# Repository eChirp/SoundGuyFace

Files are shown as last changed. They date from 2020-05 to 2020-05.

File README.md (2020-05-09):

# SoundGuyFace
This is a simple USB audio interface using the Texas Instruments 2912A. The IC is a single chip solution for standard audio needs with a computer. Professional microphones use the XLR connector and have differential signals. The SoundGuyFace takes both, microphone and instrument 1/4" cables. A dedicated gain knob let you choose the input sensitivity.

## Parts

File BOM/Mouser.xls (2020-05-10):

Mfr Part Number (Input) | Manufacturer Part Number | Mouser Part Number | Manufacturer Name | Description | Quantity 1 | Unit Price 1 | Quantity 2 | Unit Price 2 | Quantity 3 | Unit Price 3 | Quantity 4 | Unit Price 4 | Quantity 5 | Unit Price 5 | Order Quantity | Order Unit Price | Min./Mult. | Availability | Lead Time in Days | Lifecycle | NCNR | RoHS | Pb Free | Package Type | Datasheet URL | Product Image | Design Risk
 |  | 710-860020373010 | Wurth Elektronik |  | 2
 |  | 581-08055D475KAT2A | AVX |  | 4
 |  | 710-885012205052 | Wurth Elektronik |  | 2
 |  | 710-860020772010 | Wurth Elektronik |  | 2
 |  | 710-885012005007 | Wurth Elektronik |  | 1
 |  | 710-860010672002 | Wurth Elektronik |  | 1
 |  | 963-UMK212BJ105MG-T | Taiyo Yuden |  | 1
 |  | 710-885012005013 | Wurth Elektronik |  | 2
 |  | 810-C1005X5R1A335K0C | TDK |  | 2
 |  | 791-0603N251J500CT | Walsin |  | 1
 |  | 963-LMK105BJ105MVHF | Taiyo Yuden |  | 9
 |  | 80-C0402C390J5G | KEMET |  | 2
 |  | 583-FM5819 | Rectron |  | 3
 |  | 604-AA3021ES | Kingbright |  | 1
 |  | 604-AA3021SGS | Kingbright |  | 1
 |  | 550-20384 |  |  | 1
 |  | 568-NCJ6FA-H-0 | Neutrik |  | 1
 |  | 490-UJ2-MIBH-4-MSMT |  |  | 1
 |  | 710-74404064220 | Wurth Elektronik |  | 1
 |  | 710-74479276210C | Wurth Elektronik |  | 1
 |  | 71-CRCW04021K00FKEDC | Vishay / Dale |  | 6
 |  | 71-CRCW04026K80FKED | Vishay / Dale |  | 3
 |  | 755-SFR01MZPF3301 | ROHM Semiconductor |  | 4
 |  | 71-CRCW040247K0FKEDC | Vishay / Dale |  | 2
 |  | 667-ERJ-2RKD18R0X | Panasonic |  | 2
 |  | 755-SFR01MZPF2702 | ROHM Semiconductor |  | 1
 |  | 603-RC0100JR-071K5L | Yageo |  | 1
 |  | 755-SFR01MZPF22R0 | ROHM Semiconductor |  | 2
 |  | 755-SFR01MZPJ105 | ROHM Semiconductor |  | 2
 |  | 71-CRCW040220K0FKEDC | Vishay / Dale |  | 1
 |  | 595-INA333AIDGKR | Texas Instruments |  | 1
 |  | 595-TPS61040DBVR | Texas Instruments |  | 1
 |  | 81-CSTNR6M00GH5L000R |  |  | 1

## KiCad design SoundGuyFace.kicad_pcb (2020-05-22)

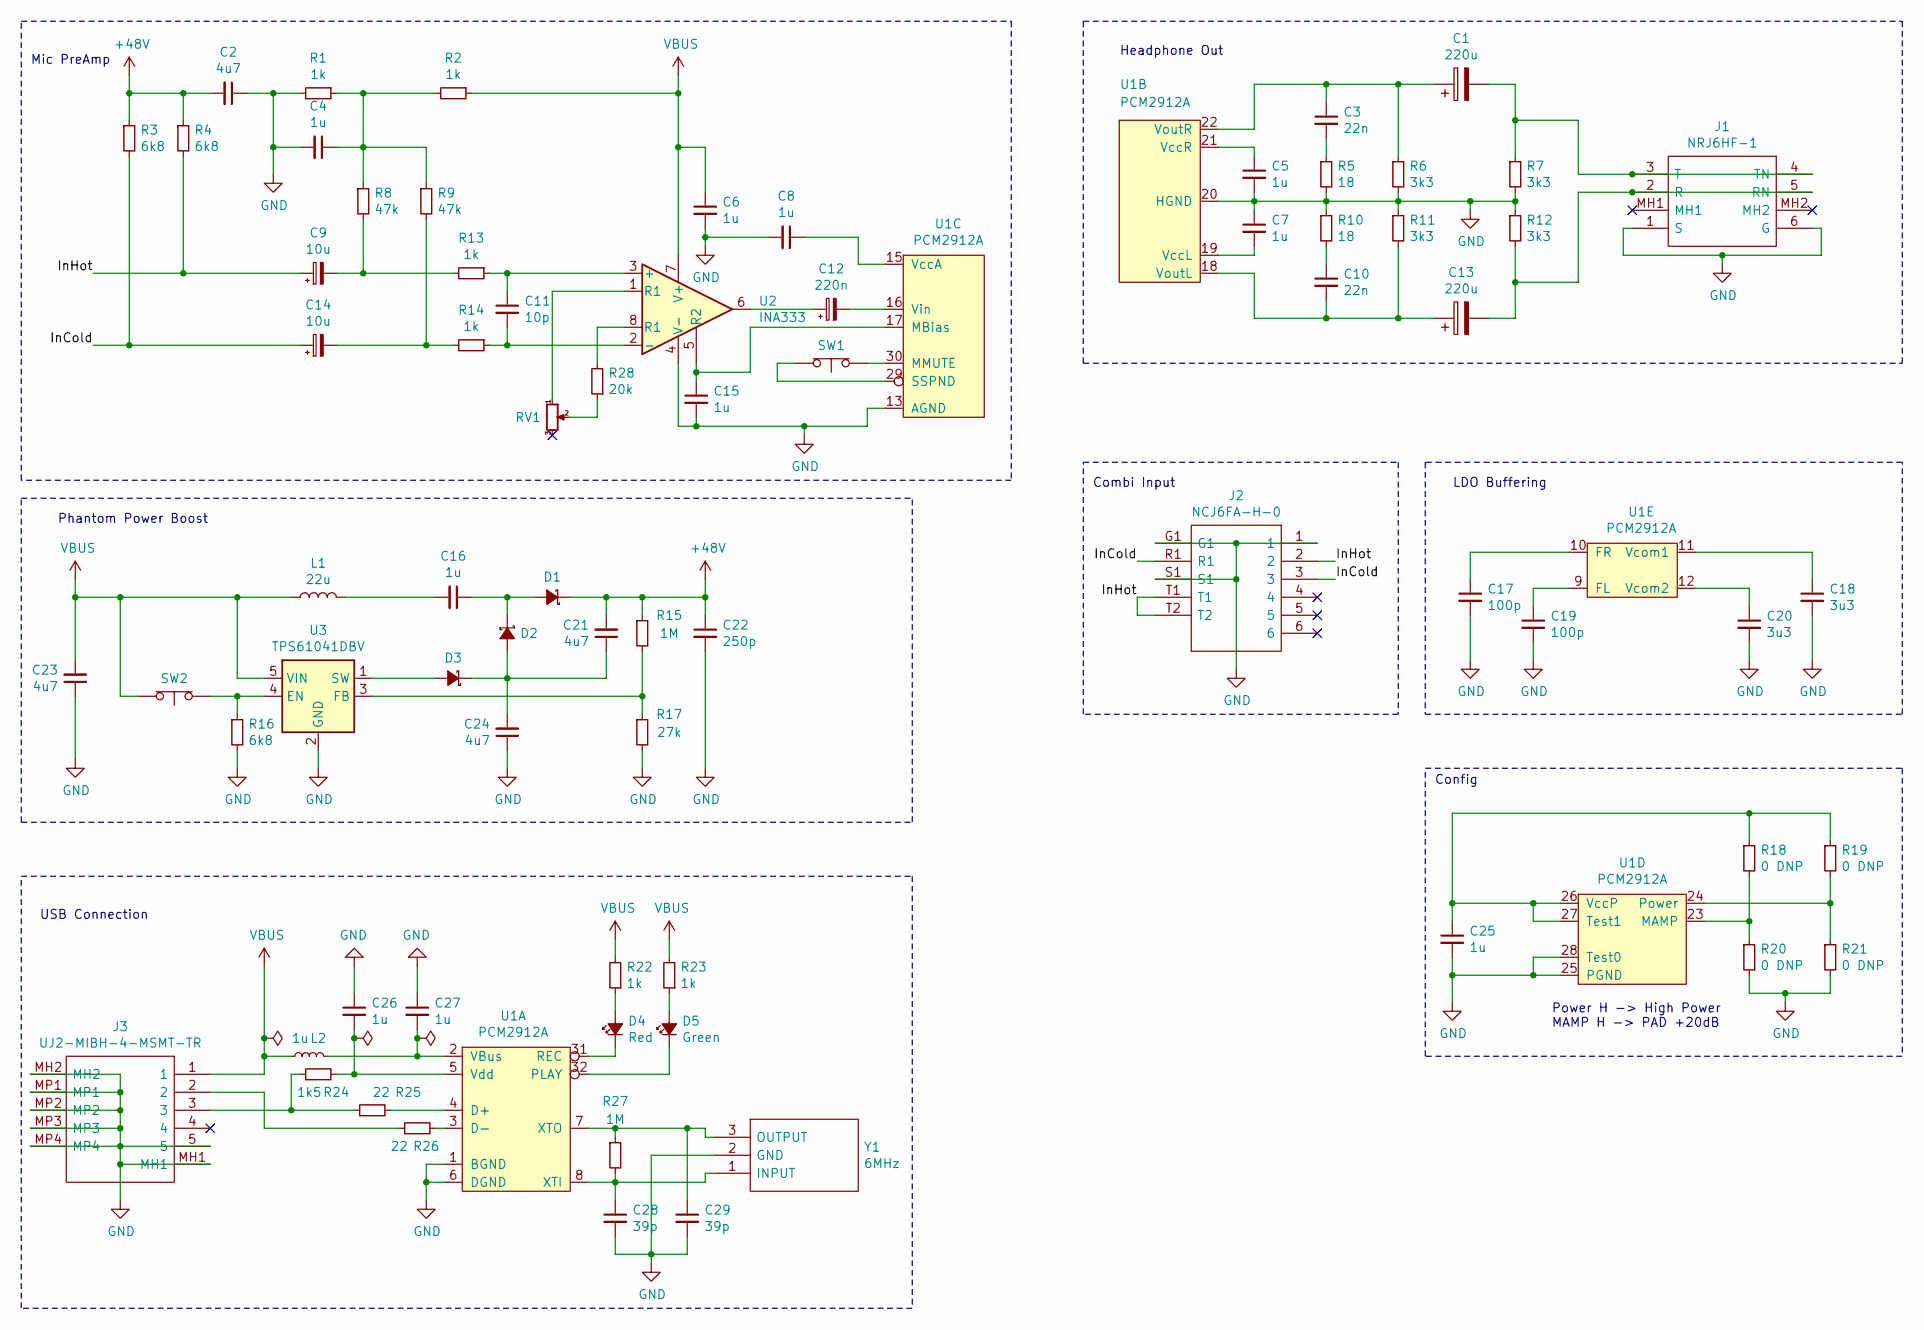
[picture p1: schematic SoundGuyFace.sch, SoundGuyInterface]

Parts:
C1, C13: 220u; CP_Radial_D6.3mm_P2.50mm; Manufacturer Part ID 860020373010; Mouser ID 710-860020373010
C2, C21, C23, C24: 4u7; C_0402_1005Metric; Manufacturer Part ID 08055D475KAT2A; Mouser ID 581-08055D475KAT2A
C3, C10: 22n; C_0402_1005Metric; Manufacturer Part ID 885012205052; Mouser ID 710-885012205052
C4, C5, C6, C7, C8, C15, C25, C26, C27: 1u; C_0402_1005Metric; Manufacturer Part ID LMK105BJ105MVHF; Mouser ID 963-LMK105BJ105MVHF
C9, C14: 10u; CP_Radial_D5.0mm_P2.00mm; Manufacturer Part ID 860020772010; Mouser ID 710-860020772010
C11: 10p; C_0402_1005Metric; Manufacturer Part ID 885012005007; Mouser ID 710-885012005007
C12: 220n; CP_Radial_D5.0mm_P2.00mm; Manufacturer Part ID 860010672002; Mouser ID 710-860010672002
C16: 1u; C_0805_2012Metric; Manufacturer Part ID UMK212BJ105MG-T; Mouser ID 963-UMK212BJ105MG-T
C17, C19: 100p; C_0402_1005Metric; Manufacturer Part ID 885012005013; Mouser ID 710-885012005013
C18, C20: 3u3; C_0402_1005Metric; Manufacturer Part ID C1005X5R1A335K050BC; Mouser ID 810-C1005X5R1A335K0C
C22: 250p; C_0603_1608Metric; Manufacturer Part ID 0603N251J500CT; Mouser ID 791-0603N251J500CT
C28, C29: 39p; C_0402_1005Metric; Manufacturer Part ID C0402C390J5GACTU; Mouser ID 80-C0402C390J5G
D1, D2, D3: D_Schottky_Small_ALT; D_SMA_Handsoldering; Manufacturer Part ID FM5819-W; Mouser ID 583-FM5819
D4: Red; D_1210_3225Metric; Manufacturer Part ID AA3021ES; Mouser ID 604-AA3021ES
D5: Green; D_1210_3225Metric; Manufacturer Part ID AA3021SGS; Mouser ID 604-AA3021SGS
J1: NRJ6HF-1; NRJ6HF1; Mouser Part Number 550-20384
J2: NCJ6FA-H-0; NCJ6FAH0; Mouser Part Number 568-NCJ6FA-H-0
J3: UJ2-MIBH-4-MSMT-TR; UJ2MIBH4MSMTTR; Mouser Part Number 490-UJ2-MIBH-4-MSMT
L1: 22u; INDPM6060X450N; Manufacturer Part ID 74404064220; Mouser ID 710-74404064220
L2: 1u; L_0805_2012Metric; Manufacturer Part ID 74479276210C; Mouser ID 710-74479276210C
R1, R2, R13, R14, R22, R23: 1k; R_0402_1005Metric; Manufacturer Part ID CRCW04021K00FKEDC; Mouser ID 71-CRCW04021K00FKEDC
R3, R4, R16: 6k8; R_0402_1005Metric; Manufacturer Part ID CRCW04026K80FKED; Mouser ID 71-CRCW04026K80FKED
R5, R10: 18; R_0402_1005Metric; Manufacturer Part ID ERJ2RKD18R0X; Mouser ID 667-ERJ-2RKD18R0X
R6, R7, R11, R12: 3k3; R_0402_1005Metric; Manufacturer Part ID SFR01MZPF3301; Mouser ID 755-SFR01MZPF3301
R8, R9: 47k; R_0402_1005Metric; Manufacturer Part ID CRCW040247K0FKEDC; Mouser ID 71-CRCW040247K0FKEDC
R15, R27: 1M; R_0402_1005Metric; Manufacturer Part ID SFR01MZPJ105; Mouser ID 755-SFR01MZPJ105
R17: 27k; R_0402_1005Metric; Manufacturer Part ID SFR01MZPF2702; Mouser ID 755-SFR01MZPF2702
R18, R19, R20, R21: 0 DNP; R_0201_0603Metric
R24: 1k5; R_0402_1005Metric; Manufacturer Part ID RC0100JR-071K5L; Mouser ID 603-RC0100JR-071K5L
R25, R26: 22; R_0402_1005Metric; Manufacturer Part ID SFR01MZPF22R0; Mouser ID 755-SFR01MZPF22R0
R28: 20k; R_0402_1005Metric; Manufacturer Part ID CRCW040220K0FKEDC; Mouser ID 71-CRCW040220K0FKEDC
RV1: R_POT_Small; Potentiometer_Alps_RK097_Dual_Horizontal
SW1, SW2: SW_Push_Open; PinHeader_1x02_P2.54mm_Vertical
U1: PCM2912A; TQFP-32_7x7mm_P0.8mm
U2: INA333; VSSOP-8_3.0x3.0mm_P0.65mm; Manufacturer Part ID INA333AIDGKR; Mouser ID 595-INA333AIDGKR
U3: TPS61041DBV; SOT-23-5; Manufacturer Part ID TPS61040DBVR; Mouser ID 595-TPS61040DBVR
Y1: 6MHz; CSTNR6M00GH5L000R0; Mouser Part Number 81-CSTNR6M00GH5L000R

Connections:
+48V: C2.2, C21.2, C22.1, D1.1 (K), R3.1, R4.1, R15.1
/InCold: C14.1, J2.3, J2.R1, R3.2
/InHot: C9.1, J2.2, J2.T1, J2.T2, R4.2
GND: C2.1, C4.2, C5.2, C6.2, C7.1, C8.2, C15.2, C17.2, C18.2, C19.2, C20.2, C22.2, C23.1, C24.1, C25.2, C26.1, C27.1, C28.2, C29.2, J1.1 (S), J1.6 (G), J2.1, J2.G1, J2.S1, J3.5, J3.MH1, J3.MH2, J3.MP1, J3.MP2, J3.MP3, J3.MP4, R1.2, R5.2, R6.2, R7.2, R10.1, R11.1, R12.1, R16.2, R17.2, R20.2, R21.2, U1.1 (BGND), U1.6 (DGND), U1.13 (AGND), U1.20 (HGND), U1.25 (PGND), U1.28 (Test0), U2.4 (V-), U3.2 (GND), Y1.2 (GND)
unnamed: C1.1, C3.1, R6.1, U1.22 (VoutR)
unnamed: C1.2, J1.3 (T), J1.4 (TN), R7.1
unnamed: C3.2, R5.1
unnamed: C4.1, R1.1, R2.2, R8.1, R9.1
unnamed: C5.1, U1.21 (VccR)
unnamed: C7.2, U1.19 (VccL)
unnamed: C8.1, U1.15 (VccA)
unnamed: C9.2, R8.2, R13.2
unnamed: C10.1, R10.2
unnamed: C10.2, C13.1, R11.2, U1.18 (VoutL)
unnamed: C11.1, R13.1, U2.3 (+)
unnamed: C11.2, R14.1, U2.2 (-)
unnamed: C12.1, U2.6
unnamed: C12.2, U1.16 (Vin)
unnamed: C13.2, J1.2 (R), J1.5 (RN), R12.2
unnamed: C14.2, R9.2, R14.2
unnamed: C15.1, U1.17 (MBias), U2.5 (R2)
unnamed: C16.1, D1.2 (A), D2.1 (K)
unnamed: C16.2, L1.2
unnamed: C17.1, U1.10 (FR)
unnamed: C18.1, U1.11 (Vcom1)
unnamed: C19.1, U1.9 (FL)
unnamed: C20.1, U1.12 (Vcom2)
unnamed: C21.1, C24.2, D2.2 (A), D3.1 (K)
unnamed: C25.1, R18.1, R19.1, U1.26 (VccP), U1.27 (Test1)
unnamed: C26.2, R24.2, U1.5 (Vdd)
unnamed: C27.2, L2.2, U1.2 (VBus)
unnamed: C28.1, R27.2, U1.8 (XTI), Y1.1 (INPUT)
unnamed: C29.1, R27.1, U1.7 (XTO), Y1.3 (OUTPUT)
unnamed: D3.2 (A), U3.1 (SW)
unnamed: D4.1 (K), U1.31 (REC)
unnamed: D4.2 (A), R22.1
unnamed: D5.1 (K), U1.32 (PLAY)
unnamed: D5.2 (A), R23.1
unnamed: J3.2, R26.1
unnamed: J3.3, R24.1, R25.1
unnamed: R15.2, R17.1, U3.3 (FB)
unnamed 47: R16.1, SW2.2 (B), U3.4 (EN); also elsewhere on the board
unnamed: R18.2, R20.1, U1.23 (MAMP)
unnamed: R19.2, R21.1, U1.24 (Power)
unnamed: R25.2, U1.4 (D+)
unnamed: R26.2, U1.3 (D-)
unnamed: R28.1, RV1.2
unnamed: R28.2, U2.8 (R1)
unnamed: RV1.1, U2.1 (R1)
unnamed 56: SW1.1 (A), U1.29 (SSPND); also elsewhere on the board
unnamed 57: SW1.2 (B), U1.30 (MMUTE); also elsewhere on the board
VBUS: C6.1, C23.2, J3.1, L1.1, L2.1, R2.1, R22.2, R23.2, SW2.1 (A), U2.7 (V+), U3.5 (VIN); also elsewhere on the board

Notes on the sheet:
Power H -> High Power MAMP H -> PAD +20dB
LDO Buffering
Headphone Out
Config
Mic PreAmp
USB Connection
Combi Input
Phantom Power Boost

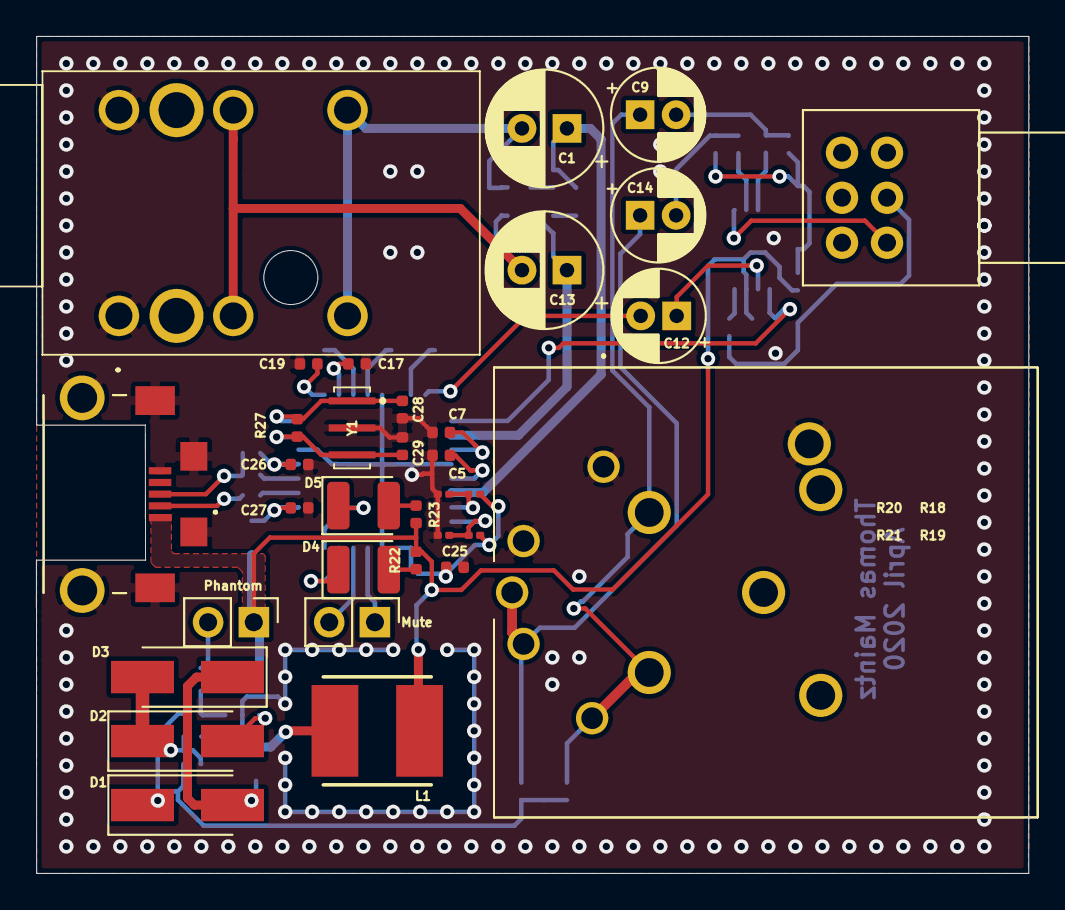
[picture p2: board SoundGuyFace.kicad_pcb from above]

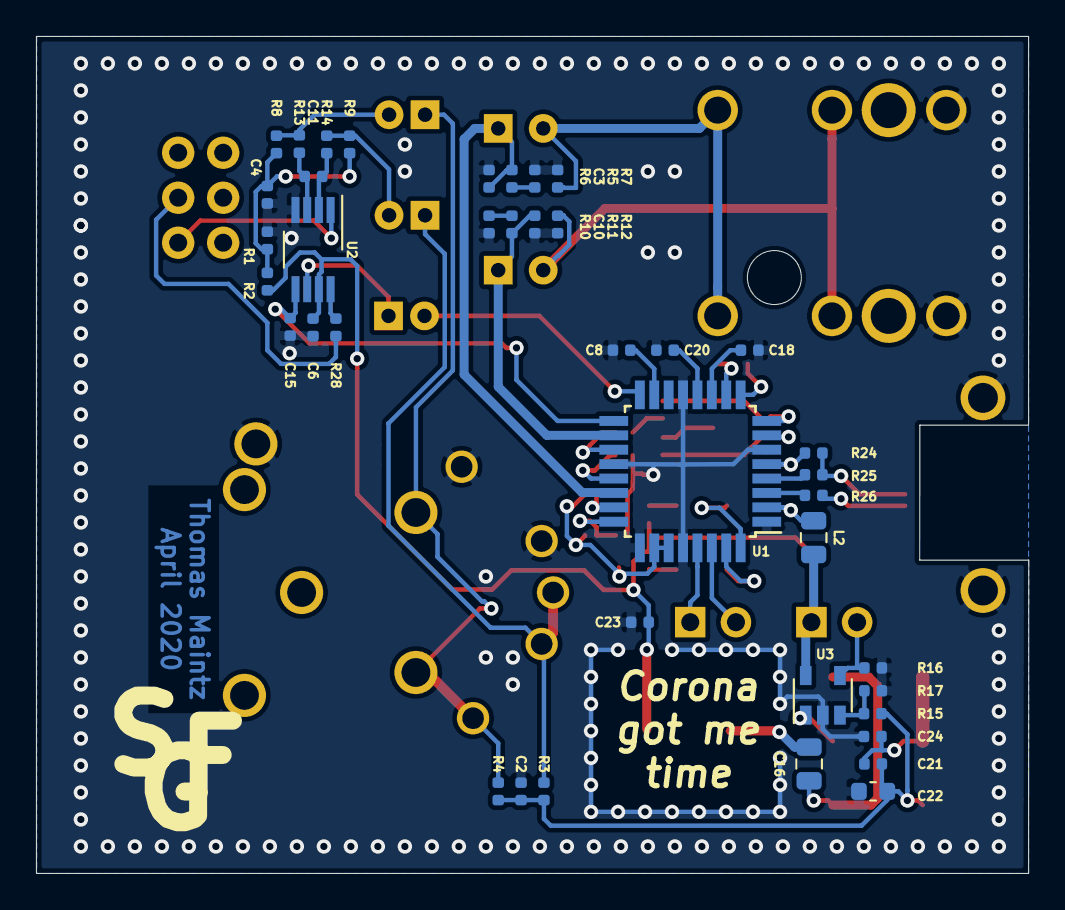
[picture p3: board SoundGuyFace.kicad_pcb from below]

Board: 2 copper layers, 55.1 x 46.5 mm, 74 parts (40 on the bottom side), 52 nets.

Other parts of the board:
Mute: SW_Push_Open; PinHeader_1x02_P2.54mm_Vertical
Phantom: SW_Push_Open; PinHeader_1x02_P2.54mm_Vertical

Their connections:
unnamed 47: Phantom.2; also elsewhere on the board
unnamed 56: Mute.1; also elsewhere on the board
unnamed 57: Mute.2; also elsewhere on the board
VBUS: Phantom.1; also elsewhere on the board

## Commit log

2020-05-09 Initial KiCAD project commit
    [SoundGuyFace.kicad_pcb, SoundGuyFace.sch]
2020-05-10 Small schematic changes and first PCB layout done
    [SoundGuyFace.kicad_pcb, SoundGuyFace.sch]
2020-05-10 Added initial BOM
    [Mouser.xls]
2020-05-10 Version to dispatch
    [SoundGuyFace.kicad_pcb, SoundGuyFace.sch]
2020-05-15 First Hardware debug. Forgot sparing for the USB connector
    [SoundGuyFace.kicad_pcb]
2020-05-22 Added outline for USB part
    [SoundGuyFace.kicad_pcb]
